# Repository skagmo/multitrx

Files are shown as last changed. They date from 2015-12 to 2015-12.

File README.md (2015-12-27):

MultiTRX - home automation transceiver
======================================

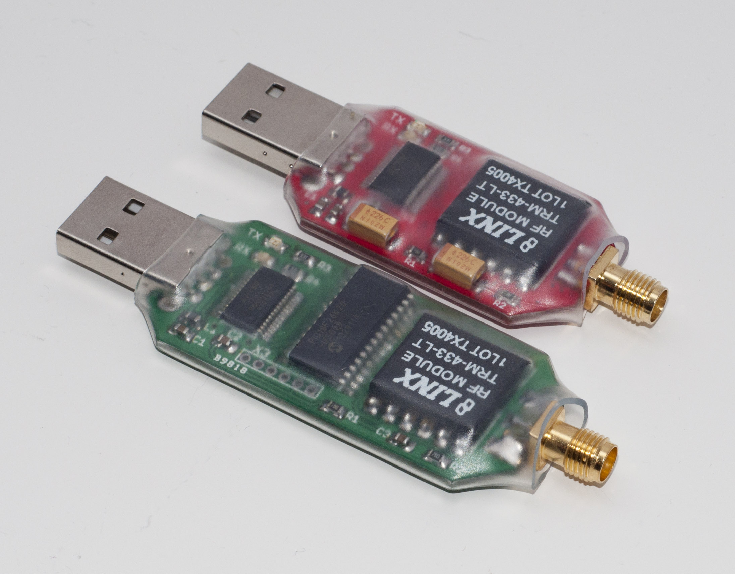
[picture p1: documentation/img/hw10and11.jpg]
multitrx


The MultiTRX is a small USB RF transceiver made to control cheap remote power switches and decode various sensors operating at 433,92 MHz. The project originates back to 2011, and was one of my first serious microcontroller projects. I have now decided to make the project open source, and at the same time releases a new firmware almost 5 years after the previous firmware was released! See "firmware/1.3/CHANGES" for details. 

Compatible with many products operating on 433,92 MHz
-----------------------------------------------------
- Nexa self learning system (decode, encode)
- Nexa code wheel system (decode)
- Kangthai power switches (encode)
- GAO power switches (decode, encode)
- Waveman power switches (encode)
- Doro PIR and door sensors (decode)
- Esic temperature sensors (decode)

Firmware project
----------------

The project is made in Microchip MPLAB X with XC8 compiler. Firmware 1.3 can be flashed to a MultiTRX hardware 1.1 (red PCB). Hardware 1.0 (green PCB) is not supported in the latest firmware because the transceiver data pin is not connected to an interrupt pin on the microcontroller. Allowing non-interrupt-driven timing for legacy devices can easily be done by looking at how timing is done in firwmare 1.2. Now it's all open source, so feel obligated ;)

To upload the firmware, use one of the two methods below:
- Connect a PIC programmer to the six exposed pads on the MultiTRX (while powered)
- For most devices sold, the microcontroller is flashed with a bootloader. Upload the ".hex"-file from "firmware/1.3/multitrx.X/dist/default/production/" using the "ds30 Loader" bootloader and instructions in "firmware/bootloader-and-compiled/"

Packet scope
------------

With firmware 1.3, the MultiTRX can forward raw samples from the ASK transceiver. This is very useful for reverse engineering more protocols.
- Verify port name and run the python program "reverse-engineering/mtrx-raw.py"
- When a sequence of bits is received above the noise level, the bit timing is printed and a plot will open in a new window
- Close the plot to allow for a new sequence to be received

HomeGenie MultiTRX addon
------------------------

Check out the add-on for HomeGenie in the subfolder "homegenie-addon".

Operation manual
----------------

The easiest way of controlling your remote power switch is to keep your (already paired) remote control close to the MultiTRX and copy the string received, eg. "$GABC2F0". This way you can switch on and off this device by sending "$GABC2F1" and "$GABC2F0", respectively.

### Gao-specific
If you want to pair a GAO device with the MultiTRX directly, send the string above, but replace the power on/off parameter with the number two: $GABC2F2.

### Nexa-specific
Nexa dimmers has the great feature of being able to dim to an absolute level in 16 steps. To do so, replace the power on/off parameter with the number two, and add an extra hexadecimal character (upper case) with the dim level: $N1234ABC030 -> $N1234ABC032F (will set the device to maximum brightness).
Complete command list

All communication is done at 8N1 9600 baud (115200 baud for firmware 1.3 due to raw mode requiring higher data rate), ASCII-formatted data. Data sent to and received from the board is terminated with LF (ASCII character 10) or CR (ASCII character 13). All hexadecimal characters must be in upper case!

### Commands transmitted from MultiTRX (RF-reception)

| Output | Description | Example(s)  |
|:--- |:--- |:---  |
| $Dddd | Doro Secur sensor. d = dip switch settings (hex). | $DA07 |
| $Eh,c,t,H,b | Esic temperature sensor. h = house code, c = channel, t = temperature (degrees Celsius), H = relative humidity (percent), b = low battery indicator (0/1). | $E5,1,12.3,71,0 |
| $GiiicCp | GAO remote power switch. i = unique ID (hex), c = channel, C = checksum, p = power setting (0/1) | $GABC2F0 $GABC2F1 |
| $Niiiiiiigcp | Nexa remote power switch. i = unique ID (hex), g = group enable (0/1), c = channel (hex), p = power setting (0/1). Packets with dim level will not be received! | $N1234ABC010 $N1234ABC011 |

### Commands transmitted to the MultiTRX (RF-transmission)

| Input | Description | Example(s) |
|:----- |:--- |:--- |
| $GiiicCp | GAO remote power switch. i = unique ID (hex), c = channel, C = checksum, p = power setting (0/1) and pairing mode (2) | $GABC2F0 $GABC2F1 |
| $Niiiiiiigcp[l] | Nexa remote power switch. i = unique ID (hex), g = group enable (0/1), c = channel (hex), p = power setting (0/1, absolute dim level = 2), l = dim level (hex). Dim level only applies if p = 2, so the length of this string varies. | $N1234ABC010 $N1234ABC011 $N1234ABC012F |
| $Whuup | Waveman remote power switch. h = house code (A-P), uu = unit code (01-16), p = power setting (0/1) | $WA011 |
| $Kssssscp | Kangtai remote power switch. s = system code dip switch (0/1), c = channel (A-E), p = power setting (0/1) | $K00001A1 |
| $Bd | See above. | - |

### Other commands transmitted to the MultiTRX

| Input | Description | Example(s) |
|:----- |:--- |:--- |
| $S | Print all settings. Settings can be changed by typing the character shown in brackets after typing "$S". | - |
| $P | The MultiTRX will respond with version number | - |
| $X | Force restart. Primarily used to upload new firmware with bootloader. | - |
| $Sp | Execute setting p (for commands with no value) | $SF (to load defaults) |
| $Spv | Set setting "p" to value "v" | $SD0 (to deactivate Doro-reception) | 

--
Jon Petter Skagmo, LA3JPA

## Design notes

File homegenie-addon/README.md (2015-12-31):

HomeGenie MultiTRX addon
========================

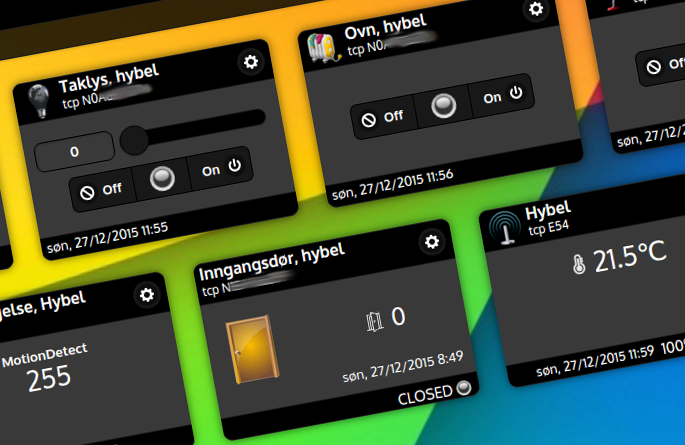
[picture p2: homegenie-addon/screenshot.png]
HomeGenie screenshot


After discovering many alternatives for home automation such as "HomeGenie", "OpenHAB" and "Domoticz", I've skipped further development of "Device Control Center" which was made for the MultiTRX. The scope of making a full home automation daemon, a nice web-UI and an android app is way too large, and the available alternatives are just getting better and better.

HomeGenie was chosen over the other platforms because:
- The web-interface is far ahead of its competitors. It looks very modern and is quick and reponsive
- It has a free Android app, as well as more sophisticated and slick non-free app (HomeGenie Plus)
- It has a comprehensive API and powerful scripting in C#
- It is easy to interface with new hardware

Getting started
---------------

- Go to "Configure", "Programs", then add a new group or enter an existing group
- Go to "Actions", "Import program", and select the "MultiGenie.hgx"-file from this repository
- When the program is imported, click on it to set options such as port and baud rate, then click "restart" to run the program
- As devices are received, they will be added as modules in HomeGenie

Add modules to a group:
- Go to "Configure", "Groups", select a group
- Go to to "Actions", "Add Module", and select one of the discovered modules under the domain "HomeAutomation.MultiTRX.serial"

Now you can control your lights with an Android app, PIR sensor activity, scheduled events such as sunset/sunrise, etc.

If you are using a NEXA dimmer, configure the module to be of a "Dimmer" type, rather than "Switch" or "Light".

Using a remote MultiTRX device
------------------------------

To extend coverage, you can connect another MultiTRX to for example a Raspberry Pi and place it in a remote part of your house. Run a TCP-server with socat to make it available for HomeGenie.

Remote device running Linux:
- Set baud rate with for example "stty -F /dev/ttyUSB0 115200"
- Run socat in background or screen with something like "socat TCP-LISTEN:1340,fork,reuseaddr /dev/ttyUSB0,echo=0,unlink-close=0"

HomeGenie server:
- Configure HomeGenie to connect to the remote device by setting the hostname property in MultiGenie

--
Jon Petter Skagmo, LA3JPA

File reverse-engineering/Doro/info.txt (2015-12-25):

HT12E encoder:
A0-A7 = DIP 1-8

D00F (Delay)
D007 (Instant)
D003 (Tamper)

H52PBZT
PCHA52P2A0A

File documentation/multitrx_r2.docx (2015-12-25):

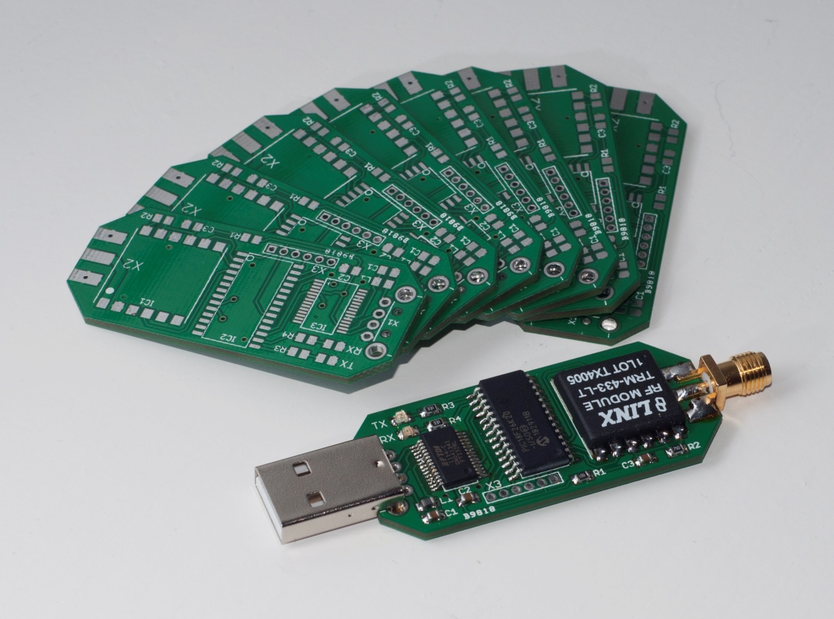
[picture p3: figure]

# MultiTRX, firmware 1.0

# Operating manual

Second revision

Jon Petter Skagmo 2011 - skagmo.com

Contents

# Introduction and overview

Tons of wireless sensors, remote power switches, alarms etc. use the 433.92 MHz ISM band for wireless transmission of data. Unfortunately, not many of these products can be easily controlled with a computer. The MultiTRX aims to solve the problem of easily decoding and encoding of signals from cheap consumer electronics from stores like Clas Ohlson. It does a lot of things not present in any other device. Among other exiting features it decodes and encodes the unique ID of remote power switches, enabling you to keep the pairing with your existing remote control.

# Getting started

Once plugged in, the MultiTRX will appear as a serial port on your computer. On Windows systems, check device manager to find out which COM-port number has been assigned to the device. On Linux based systems, the device will appear in /dev/ as ttyUSBx.

The MultiTRX will light both leds for 2.5 seconds, which indicates that the MultiTRX is ready to accept a firmware update. If a boot loader is not detected, both leds will flash rapidly. This indicates a successful startup.

To test the device in Windows, download a serial terminal software like PuTTY, and start a serial session at 9600 baud (8N1). Go to Change Settings..., Terminal and click Implicit CR in every LF. Send $P to the device and you should receive the version number. Data received from RF should now appear in the terminal as they are received.

# Receiving data

The MultiTRX can decode data from Esic temperature sensors, Doro Secur sensors and Nexa and GAO remote controls. See the complete command list on the next page.

## Sabotage control

To make sure this device will not be used to sabotage other users of remote power switches, a software limit on reception of Nexa and GAO devices has been added. This limit disables printing of these devices until at certain number of equal packets has been received. This means you have to hold the button on your remote a few seconds before the full packet is shown. It is however still possible to let the MultiTRX print your remote control ID at the first packet received if you have stored it's unique ID in the MultiTRXs EEPROM ID-memory. Doing so is described in a these steps:

1. Hold your remote close to the MultiTRX and transmit until a full packet is shown in your terminal. Pay attention to the unique ID (GAO devices have a three hex character ID, and Nexa devices have a seven character unique ID, check the command list for details).

Let's say you receive the Nexa-string $N1234ABC030. The unique ID is then 1234ABC.

2. Save the data in the ID-memory by writing $S01234ABC0. The first 0 after the S is the memory location. Memory 1-8 are all valid choices. The next seven digits is the unique ID, and the leading zero is a padding character. This command needs the ID to be exactly eight characters, so if the ID is shorter than eight characters, add extra zeros until the MultiTRX prints $OK.
3. Type $R to read all eight positions of the ID-memory, just to check that your recently added ID is there

# Controlling power-switches

The easiest way of controlling your remote power switch is to keep your (already paired) remote control close to the MultiTRX and copy the string received, eg. $GABC2F0. This way you can switch on and off this device by sending $GABC2F1 and $GABC2F0 , respectively.

## Gao-specific

If you want to pair a GAO device with the MultiTRX directly, send the string above, but replace the power on/off parameter with the number two: $GABC2F2.

## Nexa-specific

Nexa dimmers has the great feature of being able to dim to an absolute level in 16 steps. To do so, replace the power on/off parameter with the number two, and add an extra hexadecimal character (upper case) with the dim level: $N1234ABC030 -> $N1234ABC032F (will set the device to maximum brightness).

# Complete command list

All communication is done at 8N1 9600 baud, ASCII-formatted data. Data from the board is terminated with LF (ASCII character 10). Data sent to the board does not need any kind of termination, as the commands are fixed length. All hexadecimal characters must be in upper case!

## Commands transmitted from MultiTRX (RF-reception)

Output | Description | Example(s)
$Dddd | Doro Secur sensor. d = dip switch settings (hex). | $DA07
$Eh,c,t,H | Esic temperature sensor. h = house code, c = channel, t = temperature (degrees Celsius), H = relative humidity (percent). | $E5,1,12.3,71
$Giiiiip | GAO remote power switch. i = unique ID (hex), p = power setting (0/1) and pairing mode (2). | $GABC2F0 $GABC2F1
$Niiiiiiigcp | Nexa remote power switch. i = unique ID (hex), g = group enable (0/1), c = channel (hex), p = power setting (0/1). Packets with dim level will not be received! | $N1234ABC010 $N1234ABC011

## Commands transmitted to the MultiTRX (RF-transmission)

Input | Description | Example(s)
$GiiicCp | GAO remote power switch. i = unique ID (hex), c = channel, C = checksum, p = power setting (0/1) and pairing mode (2) | $GABC2F0 $GABC2F1
$Niiiiiiigcp(l) | Nexa remote power switch. i = unique ID (hex), g = group enable (0/1), c = channel (hex), p = power setting (0/1, absolute dim level = 2), l = dim level (hex). Dim level only applies if p = 2, so the length of this string varies. | $N1234ABC010 $N1234ABC011 $N1234ABC012F
$Whuup | Waveman remote power switch. h = house code (A-P), uu = unit code (01-16), p = power setting (0/1) | $WA011

## Other commands transmitted to the MultiTRX

Input | Description | Example(s)
$P | The MultiTRX will respond with version number | -
$Sniiiiiiii | Save unique IDs in the EEPROM ID-memory to avoid the sabotage control in the MultiTRX. n = EEPROM location (1-8), i = unique ID of remote control. The ID-field must be eight digits of length, so the ID might need to be padded with zeros! | $S11234ABC0 (ID = 1234ABC) $S212300000 (ID = 123)
$R | Read the ID-memory | $R12345678,ABC12340, 00000000,00000000...
$X | Force restart. Primarily used to upload new firmware with bootloader.

# Compatible hardware (http://folk.ntnu.no/skagmo/lib/exe/detail.php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)

## Sensors

- All wireless Doro Secur sensors (available from Alarm-Agenturet)
- Esic temperature sensor (available from Clas Ohlson)

## Power switches

- Self learning Nexa (available from Clas Ohlson and Jula)
- Waveman (available from Clas Ohlson)
- GAO/CO-tech (available from Clas Ohlson)

# Hardware specification

Supported devices (RX) | Esic temperature sensor, Doro Secur sensors and Gao and Nexa remote power switches
Supported devices (TX) | GAO, Nexa and Waveman remote power switches
Modulation | OOK / AM
Output power | 10 dBm
Receiver sensitivity | -112 dBm
Frequency stability | +/- 50kHz over -40 to 85 degrees Celsius

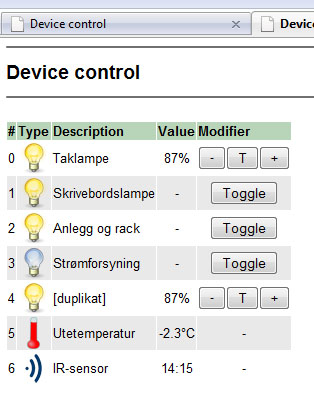
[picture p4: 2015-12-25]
documentation/img/php/inst2web.jpg

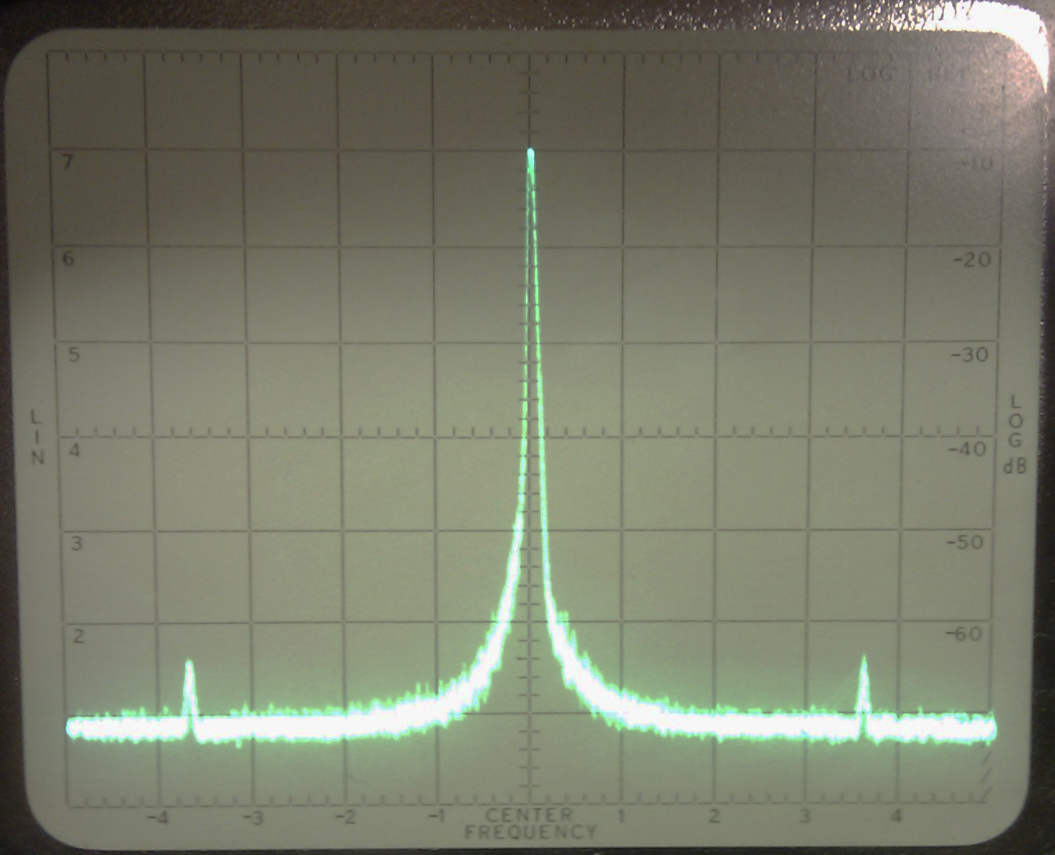
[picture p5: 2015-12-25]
documentation/img/5mhzdiv.jpg

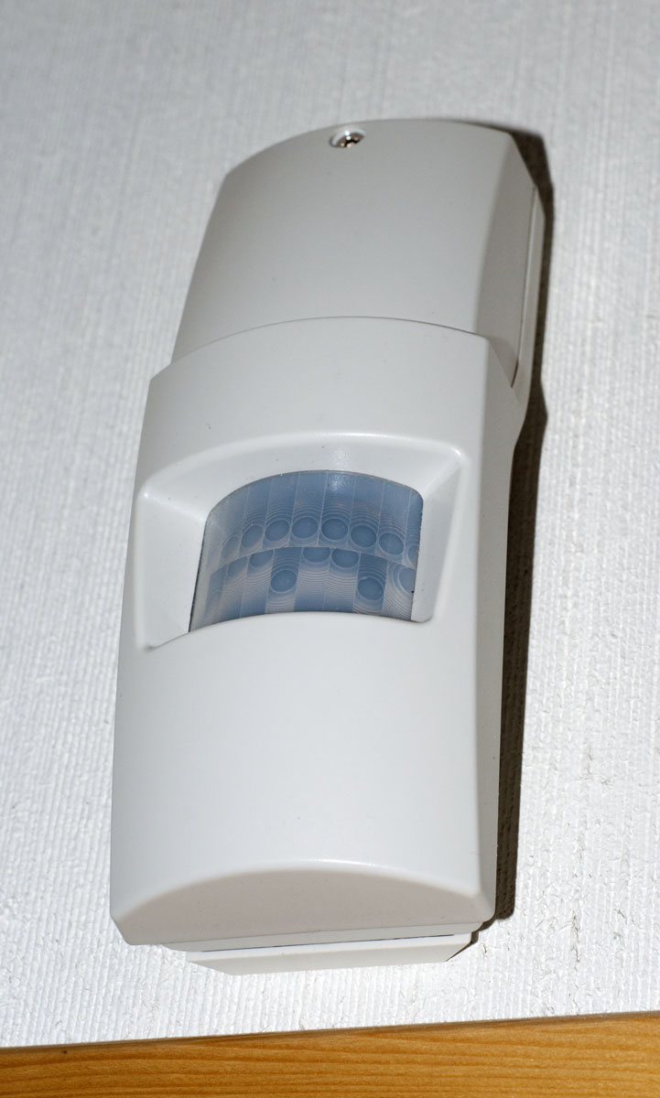
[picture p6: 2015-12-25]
documentation/img/doro_ir.jpg

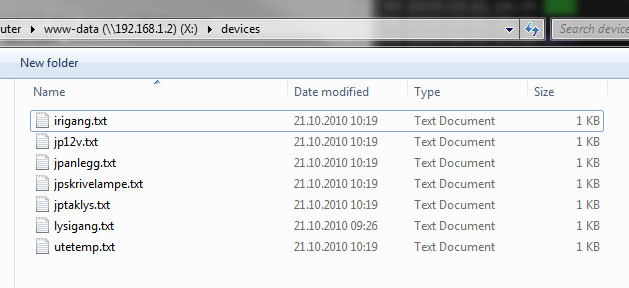
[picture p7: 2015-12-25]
documentation/img/php/devicemappe.jpg

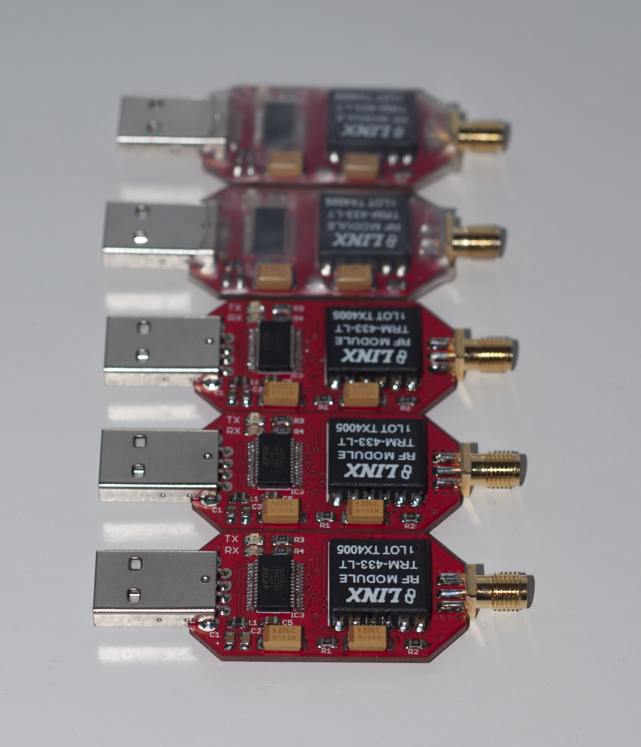
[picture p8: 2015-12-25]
documentation/img/MultiTRX HW1.1/5xhw11.jpg

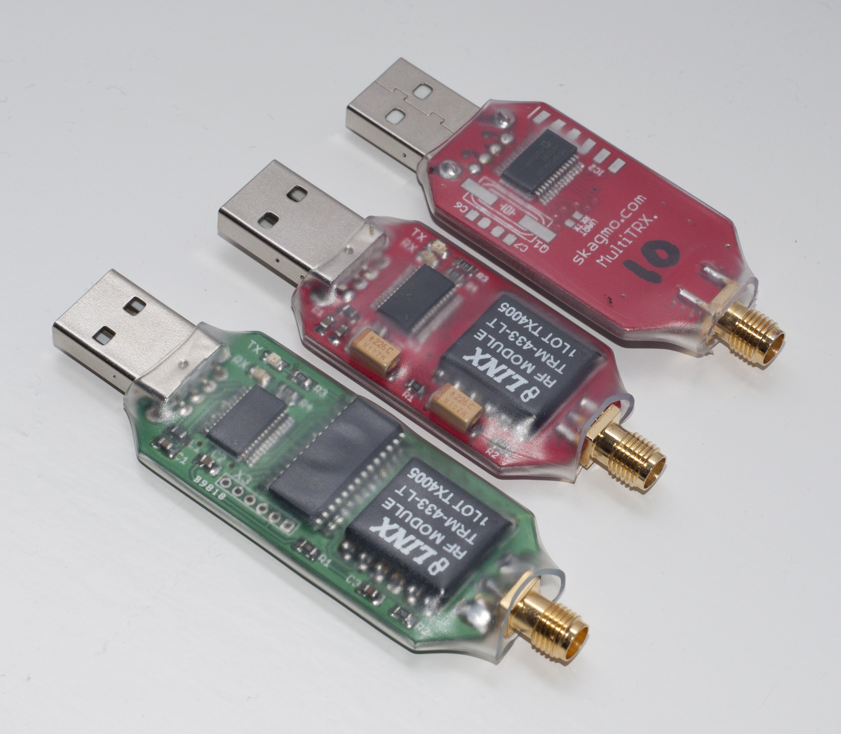
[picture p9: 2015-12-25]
documentation/img/hw10and2x11.jpg

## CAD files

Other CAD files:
firmware/1.2/multitrx2620.obj
firmware/1.3/multitrx.X/dist/default/production/multitrx.X.production.obj
firmware/1.2/startup.obj

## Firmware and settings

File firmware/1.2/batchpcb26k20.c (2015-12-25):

// MultiTRX PIC software - skagmo.com
// SW 1.2

#define _LEGACY_HEADERS
#include <htc.h>
#include "hardware_config_11.h"
#include "uartring.h"

typedef struct{
	char nr_settings;  //Must be first
	char bmc_en_rx;
	char bmc_sends;
	char bmc_en_hex;
	char bmc_repeat;
 	char bmc_hops;
	char doro_en_rx;
	char gao_en_rx;
	char gao_sends;
	char esic_en_rx;
	char nexa_en_rx;
	char nexa_sends;
	char waveman_sends;
	char kangthai_sends;
}settings_t;

void loadDefaults(settings_t *settingsp){
	settingsp->nr_settings = 14;
	settingsp->bmc_en_rx = 1;
	settingsp->bmc_sends = 2;
	settingsp->bmc_en_hex = 0;
	settingsp->bmc_repeat = 1;
 	settingsp->bmc_hops = 2;
	settingsp->doro_en_rx = 1;
	settingsp->gao_en_rx = 1;
	settingsp->gao_sends = 6;
	settingsp->esic_en_rx = 1;
	settingsp->nexa_en_rx = 1;
	settingsp->nexa_sends = 5;
	settingsp->waveman_sends = 8;
	settingsp->kangthai_sends = 6;
}settings_t;

void saveEeprom(char* settingsp){
	for (char j=0; j<settingsp[0]; j++)	eeprom_write(j, settingsp[j]);
}

void loadEeprom(char* settingsp){
	for (char j=0; j<eeprom_read(0); j++) settingsp[j] = eeprom_read(j);
}

void interrupt intRoutineHigh(void){
	sInterrupt();
}

void delayms(int ms){
	for (int counter = 0; counter < ms; counter++) __delay_ms(1);
}

void waitTimer(unsigned int value){ //Steps of approx. 1uS
	value = 0xFFFF - value;
	TMR1L = value & 0x00FF;
	TMR1H = (value & 0xFF00) >> 8;
	TMR1ON = 1;
	while(!TMR1IF);
	TMR1ON = 0;
	TMR1IF = 0;
}

char asciiToHex(char input){
	if(input <= '9') input -= '0';
	else input -= 55;
	return input;
}

char reverse(char input){
	char output = 0;
	if (input & 0b00000001) output |= 0b00001000;
	if (input & 0b00000010) output |= 0b00000100;
	if (input & 0b00000100) output |= 0b00000010;
	if (input & 0b00001000) output |= 0b00000001;
	return output;
}

void startTransmit(){
	TXLED = 1;
	TRPIN = 1;
	delayms(3);
	dataPinOut();
} 

void stopTransmit(){
	dataPinIn();
	delayms(3);
	TRPIN = 0;
	TXLED = 0;
	sPuts(ACKSTRING);
	sPut(10);
}

void startupBlinkLed(){
	char j;
	for (j = 0; j < 5; j++){
		TXLED = RXLED ^= 1;
		delayms(100);
	}
}

void blinkRxLed(){
	RXLED = 1;
	TMR3H = 0; TMR3L = 0;
	TMR3ON = 1;
}

unsigned int readAd(){
	char value = 0;
	int temp = 0;
	for (int j=0; j<1000; j++){
		ADCON0 |= 0b00000011;  // AD GO & AD enable
		while(ADCON0 & 0b00000010);  // While ~DONE
		temp = (ADRESH<<8) | ADRESL;
		temp >>= 2;
		if (temp > value) value = temp;
	}
	return value;
}

#include "bmc.h"
#include "gao.h"
#include "nexa.h"
#include "esic.h"
#include "doro.h"
#include "kangthai.h"
#include "waveman.h"

void parseSettings(char *linep, char line_len, settings_t *settingsp){
	if(line_len == 1){
		sPut(10);
		sPuts("--------- Settings ----------"); sPut(10);
		sPuts("BMC:"); sPut(10);
		sPuts(" [B] En. RX = "); sPut('0' + settingsp->bmc_en_rx);  sPut(10);
		sPuts(" [M] Sends  = "); sPut('0' + settingsp->bmc_sends); sPut(10);
		sPuts(" [C] In hex = "); sPut('0' + settingsp->bmc_en_hex);  sPut(10);
		sPuts(" [R] Repeat = "); sPut('0' + settingsp->bmc_repeat);  sPut(10);
		sPuts(" [H] Hops   = "); sPut('0' + settingsp->bmc_hops);  sPut(10);
		sPuts("Doro:"); sPut(10);
		sPuts(" [D] En. RX = "); sPut('0' + settingsp->doro_en_rx);  sPut(10);
		sPuts("GAO:"); sPut(10);
		sPuts(" [G] En. RX = "); sPut('0' + settingsp->gao_en_rx);  sPut(10);
		sPuts(" [A] Sends  = "); sPut('0' + settingsp->gao_sends); sPut(10);
		sPuts("Esic:"); sPut(10);
		sPuts(" [E] En. RX = "); sPut('0' + settingsp->esic_en_rx);  sPut(10);
		sPuts("Nexa:"); sPut(10);
		sPuts(" [N] En. RX = "); sPut('0' + settingsp->nexa_en_rx);  sPut(10);
		sPuts(" [X] Sends  = "); sPut('0' + settingsp->nexa_sends); sPut(10);
		sPuts("Waveman:"); sPut(10);
		sPuts(" [W] Sends  = "); sPut('0' + settingsp->waveman_sends); sPut(10);
		sPuts("Kangthai:"); sPut(10);
		sPuts(" [K] Sends  = "); sPut('0' + settingsp->kangthai_sends); sPut(10);
		sPuts("Settings:"); sPut(10);
		sPuts(" [S] EEPROM save"); sPut(10);
		sPuts(" [L] EEPROM load"); sPut(10);
		sPuts(" [F] Load defaults"); sPut(10);
		sPuts("Other:"); sPut(10);
		sPuts(" Curr. RSSI = "); sPutint(readAd()); sPut(10);
	}
	else{
		switch (linep[0]){
			case 'B':
				settingsp->bmc_en_rx = linep[1] - '0';
				sPuts(ACKSTRING);
				sPut(10);
				break;
			case 'M':
				settingsp->bmc_sends = linep[1] - '0';
				sPuts(ACKSTRING);
				sPut(10);
				break;
			case 'C':
				settingsp->bmc_en_hex = linep[1] - '0';
				sPuts(ACKSTRING);
				sPut(10);
				break;
			case 'R':
				settingsp->bmc_repeat = linep[1] - '0';
				sPuts(ACKSTRING);
				sPut(10);
				break;
			case 'H':
				settingsp->bmc_hops = linep[1] - '0';
				sPuts(ACKSTRING);
				sPut(10);
				break;
			case 'D':
				settingsp->doro_en_rx = linep[1] - '0';
				sPuts(ACKSTRING);
				sPut(10);
				break;
			case 'G':
				settingsp->gao_en_rx = linep[1] - '0';
				sPuts(ACKSTRING);
				sPut(10);
				break;
			case 'A':
				settingsp->gao_sends = linep[1] - '0';
				sPuts(ACKSTRING);
				sPut(10);
				break;				
			case 'E':
				settingsp->esic_en_rx = linep[1] - '0';
				sPuts(ACKSTRING);
				sPut(10);
				break;
			case 'N':
				settingsp->nexa_en_rx = linep[1] - '0';
				sPuts(ACKSTRING);
				sPut(10);
				break;
			case 'X':
				settingsp->nexa_sends = linep[1] - '0';
				sPuts(ACKSTRING);
				sPut(10);
				break;
			case 'W':
				settingsp->waveman_sends = linep[1] - '0';
				sPuts(ACKSTRING);
				sPut(10);
				break;
			case 'K':
				settingsp->kangthai_sends = linep[1] - '0';
				sPuts(ACKSTRING);
				sPut(10);
				break;
			case 'S':
				saveEeprom(settingsp);
				sPuts(ACKSTRING);
				sPut(10);
				break;
			case 'L':
				loadEeprom(settingsp);
				sPuts(ACKSTRING);
				sPut(10);
				break;
			case 'F':
				loadDefaults(settingsp);
				sPuts(ACKSTRING);
				sPut(10);
				break;
		}
	}
}

void parseCmd(char *linep, char line_len, settings_t *settingsp){
	switch(linep[1]){
		case 'G':
			if (line_len == 9) gaoTx(linep+2, settingsp->gao_sends);
			break;
		case 'W':
			if (line_len == 7) wavemanTx(linep+2, settingsp->waveman_sends);
			break;
		case 'N':
			if ((line_len >= 13)&&(line_len <= 14)) nexaTx(linep+2, settingsp->nexa_sends);
			break;
		case 'K':
			if (line_len == 10) kangthaiTx(linep+2, settingsp->kangthai_sends);
			break;
		case 'B':
			if (line_len >= 4){
				line_len -= 3; // To remove command and LF
				if(settingsp->bmc_en_hex) bmcConvertHex(linep+2, &line_len);
				bmcTx(linep+2, line_len, settingsp->bmc_hops, settingsp->bmc_sends);
			}
			break;
		case 'P':
			sPuts(STARTUPSTRING);
			sPut(10);
			break;
		case 'S':
			parseSettings(linep+2, line_len-2, settingsp);
			break;
		case 'X':
			RESET();
			break;
		case '!':
			startTransmit();
			TXPIN = 1;
			delayms(5000);
			stopTransmit();
			break;
	}
}

void main(){
	init();
	sInit(BAUDRATE);
	startupBlinkLed();
	sPuts(STARTUPSTRING);
	sPut(10);
	TRPIN = 1;
	delayms(5);
	TRPIN = 0;

	char rf_state        = 0;
	char prev_rf_state   = 0;
	char rf_pulse_length = 0;

	#define LINE_SIZE 32
	char line[LINE_SIZE];
	char line_len = 0;
	char temp_c;

	settings_t settings;
	loadEeprom(&settings);

	while(1){
		// Check RF
		rf_state = RXPIN;
		if (prev_rf_state != rf_state){
			rf_pulse_length = TMR0L;
			if(TMR0IF){    //If the timer has gone through an overflow
				rf_pulse_length = 0xFF;
				TMR0IF = 0;
			}
			TMR0L  = 0;
			if (settings.doro_en_rx) doroDecode(prev_rf_state, rf_pulse_length);
			if (settings.esic_en_rx) esicDecode(rf_pulse_length);
			if (settings.gao_en_rx)  gaoDecode (prev_rf_state, rf_pulse_length);
			if (settings.nexa_en_rx) nexaDecode(prev_rf_state, rf_pulse_length);
			if (settings.bmc_en_rx)  bmcDecode (rf_pulse_length, &settings);
		}
		prev_rf_state = rf_state;

		// Check timer flag used for RX-led
		if(TMR3IF){
			RXLED = 0;
			TMR3ON = 0;
			TMR3IF = 0;
		}

		// Check UART buffer
		while(sInWaiting()){
			temp_c = sGet();
			if(temp_c == '$') line_len = 0;
			line[line_len++] = temp_c;
			if((temp_c == 10) || (temp_c == 13)){
				if((line_len >= 3)&&(line[0]=='$')) parseCmd(&line, line_len, &settings);
				line_len = 0;
			}
		}
	}
}

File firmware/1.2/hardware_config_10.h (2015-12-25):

// BatchPCB-revision, HWID 1.0

#define STARTUPSTRING "MultiTRX HWID 1.0, FWID 1.2 - skagmo.com"
#define ACKSTRING "$OK"
#define TRPIN LATA0
#define RXPIN (PORTA&0b10)
#define TXPIN LATA1
#define TXLED LATC4
#define RXLED LATC5
#define _XTAL_FREQ 32000000
#define BAUDRATE 9600

init(){
	TRISC = 0b10000000;   //Settes i BL
	TRISB = 0b00000000;   //Settes i BL  
	TRISA = 0b00000110;   //Settes i BL
	
//	OSCCON  = 0b01100000;  // 8MHz for 26K20    //Settes i BL
//	OSCTUNE = 0b11000000;  // 4*PLL 		    //Settes i BL
	
	// Turn off all A/D
	ADCON0 = 0;  
	ANSEL  = 0;
	ANSELH = 0;
	
	// Set up timers
	//T0CON = 0b11000110;   // Used for RF-decoding //Settes i BL, 16uS step
	//T3CON = 0b00110101;   // Used for RX-LED      //Settes i BL
	T1CON = 0b01111001;   //General purpose (eg. transmission), 1uS step
	
	WDTCON = 0;    //Settes i BL

	// AD-config
	ANSEL  = 0b00000100;  // RA2 analog
	ANSELH = 0b00000000;
	ADCON0 = 0b00001001;  // AD on, RA2 aka AN2 for RSSI
	ADCON1 = 0b00000000;
	ADCON2 = 0b10111110;  // Right justified, 20 TAD, FOSC/64
}

dataPinOut(){
	TRISA  = 0b00000100;
}

dataPinIn(){
	TRISA  = 0b00000110;
}

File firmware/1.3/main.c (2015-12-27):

// MultiTRX firmware, Jon Petter Skagmo, skagmo.com

#include <xc.h>
#include "hardware_11.h"
#include "config.h"
#include "uart.h"
#include "helpers.h"
#include "sample.h"

#include "gao.h"
#include "nexa_learning.h"
#include "nexa_code.h"
#include "esic.h"
#include "doro.h"
#include "kangthai.h"
#include "waveman.h"
#include "raw.h"

void interrupt intRoutineHigh(void){
	sample_interrupt(); // Transceiver data pin interrupt
	uart_interrupt();   // UART interrupt
}

int main(){
	hardware_init();
	uart_init(BAUDRATE);
	sample_init();
	GIE = 1;
	
	#define LINE_SIZE 32
	char line[LINE_SIZE];
	char line_len = 0;

	settings_t settings;
	loadEeprom(&settings);
	
	startupBlinkLed();
	uart_puts(STARTUPSTRING);	
	enter_rx(); // Go to RX mode

	while(1){
		while (sample_tick()){
			sample_t s = sample_pop();
			if (settings.raw_en) outputRaw (s.state, s.duration, s.rssi, &settings);
			
			// Truncate to 8 bit for remaining lines
			if (s.duration>0xff) s.duration=0xff; 
			if (settings.doro_en_rx) doroDecode(s.state, s.duration);
			if (settings.esic_en_rx) esicDecode(s.duration);
			if (settings.gao_en_rx) gaoDecode(s.state, s.duration);
			if (settings.nexa_en_rx) nexaDecode(s.state, s.duration);
			if (settings.nexa_code_en) nexaCodeDecode(s.state, s.duration);
		}

		// Check timer flag used for RX-led
		if(TMR3IF){
			RXLED = 0;
			TMR3ON = 0;
			TMR3IF = 0;
		}

		// Check UART buffer
		while(uart_in_waiting()){
			char c = uart_get();
			if(c == '$') line_len = 0;
			if((c == 10) || (c == 13)){
				if((line_len >= 2)&&(line[0]=='$')) parseCmd(&line, line_len, &settings);
				line_len = 0;
			}
			if (line_len<LINE_SIZE) line[line_len++] = c;
		}
	}
}

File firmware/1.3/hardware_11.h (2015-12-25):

#ifndef HARDWARE_11_H
#define HARDWARE_11_H

// BatchPCB-revision, HWID 1.1

#include <xc.h>

#pragma config FOSC = INTIO67   // Oscillator Selection bits (Internal oscillator block, port function on RA6 and RA7)
#pragma config WDTEN = OFF      // Watchdog Timer Enable bit (WDT is controlled by SWDTEN bit of the WDTCON register)
#pragma config WDTPS = 32768    // Watchdog Timer Postscale Select bits (1:32768)
#pragma config PBADEN = OFF     // PORTB A/D Enable bit (PORTB<4:0> pins are configured as digital I/O on Reset)
#pragma config HFOFST = OFF     // HFINTOSC Fast Start-up (The system clock is held off until the HFINTOSC is stable.)
#pragma config MCLRE = OFF      // MCLR Pin Enable bit (RE3 input pin enabled; MCLR disabled)
#pragma config LVP = OFF        // Single-Supply ICSP Enable bit (Single-Supply ICSP disabled)

#define STARTUPSTRING "MultiTRX HWID 1.1, FWID 1.3 - skagmo.com\r\n"
#define ACKSTRING "$OK\r\n"
#define TRPIN LATB3
#define RXPIN (PORTB&0b100)
#define TXPIN LATB2
#define TXLED LATC4
#define RXLED LATC5
#define _XTAL_FREQ 32000000
#define BAUDRATE 115200

void hardware_init(void);
void dataPinOut(void);
void dataPinIn(void);

#endif

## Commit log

2015-12-27 Added HomeGenie addon, added UART buffer size check
2015-12-31 Added watchdog for TCP/serial in MultiGenie, added AutoClearMotion - MultiGenie will now check for a valid TCP and/or serial connection every 30 second - Added AutoClearMotion, which is a HomeGenie p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
